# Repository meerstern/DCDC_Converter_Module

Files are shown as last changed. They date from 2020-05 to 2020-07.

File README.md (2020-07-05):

# DCDC_Converter_Module
Non-insulated boost type DCDC Converter Module with ADP1612 (1.8~5.5V -> +15/-15V)

## 概要 
  * [ADP1612スイッチングコンバータ][1]を使用した昇圧電源です
  * 1.8V~5.5Vの入力で±15.1Vの出力が得られます
  * スイッチング周波数が1.3MHzと高いため、AD変換用電源やオーディオ向け電源に最適です
  * [シングル出力のスイッチングコンバータで両電源を得る(PDF,P.21電源回路参照)][2]ことでコンバータICコストの削減が可能です
  * 出力はR2,R5で決定され、デフォルトは±15.1Vで固定されています
  * 出力有効ENは内部プルアップされているため、未接続orVIN接続で出力ONします
  * それぞれ最大200mA程度の出力を得られます  
  * サイズ40mm x30mm、M3x2、間隔22mm  
  * Ni-MH電池2本2.4V電源供給、負荷100ｍAの場合、Peak-Peakで30~50mV前後、RMSで30mV前後のリップルです
    ※負荷や測定条件によって異なるため、性能を保証するものではありません  

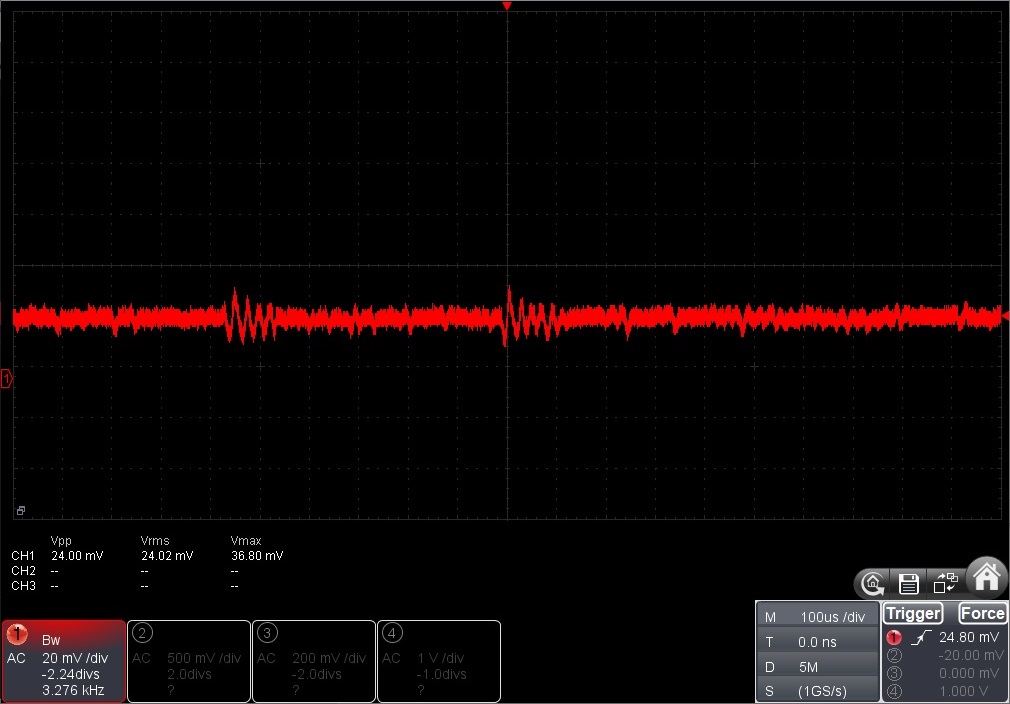
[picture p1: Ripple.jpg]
  
  
## 注意
  * ±15Vで両側に同じような負荷を接続してください
  * +15V側のみを電圧フィードバックする回路のため、負荷のアンバランスで出力電圧が不安定になる場合があります  
  * リップルを更に低減させるためには必要に応じて負荷側にコンデンサやフィルタを実装してください  

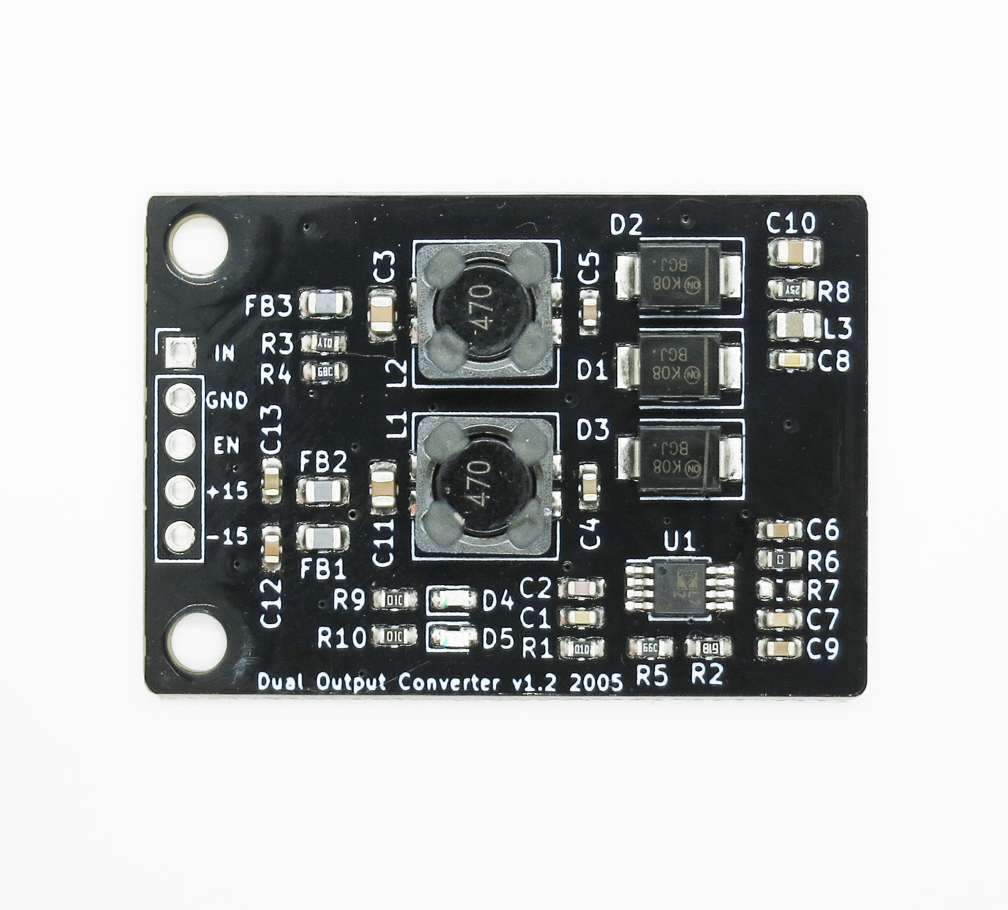
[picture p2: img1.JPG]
  
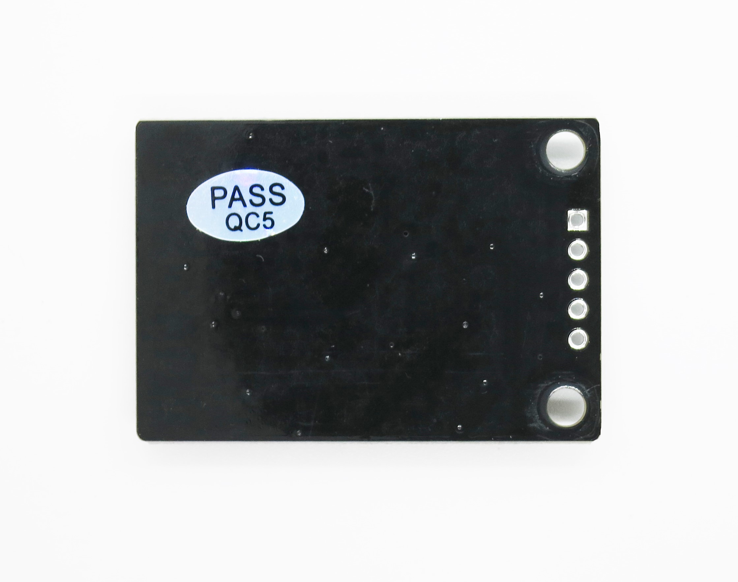
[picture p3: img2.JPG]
   

[1]: https://www.analog.com/jp/products/adp1612.html
[2]: https://www.analog.com/media/en/technical-documentation/data-sheets/ADAS3023.pdf

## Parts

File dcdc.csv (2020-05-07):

ID | 参照記号 | パッケージ | 数 | 名称 | Supplier and ref
1 | R2 | R_0603_1608Metric | 1 | 4.22k
2 | C13,C12,C9,C5,C4,C6 | C_0603_1608Metric | 6 | 1u
3 | R8 | R_0603_1608Metric | 1 | 1.8
4 | R3 | R_0603_1608Metric | 1 | 1
5 | L2,L1 | SRF0703 | 2 | 33uH
6 | H2,H1 | MountingHole_3.2mm_M3 | 2 | MountingHole
7 | L3 | L_0805_2012Metric | 1 | 1u
8 | C11,C10,C3 | C_0805_2012Metric | 3 | 10u
9 | C8 | C_0603_1608Metric | 1 | 2.2u
10 | C7 | C_0603_1608Metric | 1 | 0.1u
11 | U1 | MSOP-8_3x3mm_P0.65mm | 1 | ADP1612/ADP1613
12 | R10,R9 | R_0603_1608Metric | 2 | 10k
13 | R7 | R_0603_1608Metric | 1 | NM
14 | R6 | R_0603_1608Metric | 1 | 0
15 | R5 | R_0603_1608Metric | 1 | 47.5k
16 | R4 | R_0603_1608Metric | 1 | 50k
17 | R1 | R_0603_1608Metric | 1 | 100k
18 | J1 | PinHeader_1x05_P2.54mm_Vertical | 1 | Conn_01x05
19 | FB3,FB2,FB1 | L_0805_2012Metric | 3 | Ferrite_Bead_Small
20 | D5,D4 | D_0603_1608Metric | 2 | LED
21 | D3,D2,D1 | D_SMB | 3 | D_Schottky_ALT
22 | C2 | C_0603_1608Metric | 1 | 10p
23 | C1 | C_0603_1608Metric | 1 | 12n

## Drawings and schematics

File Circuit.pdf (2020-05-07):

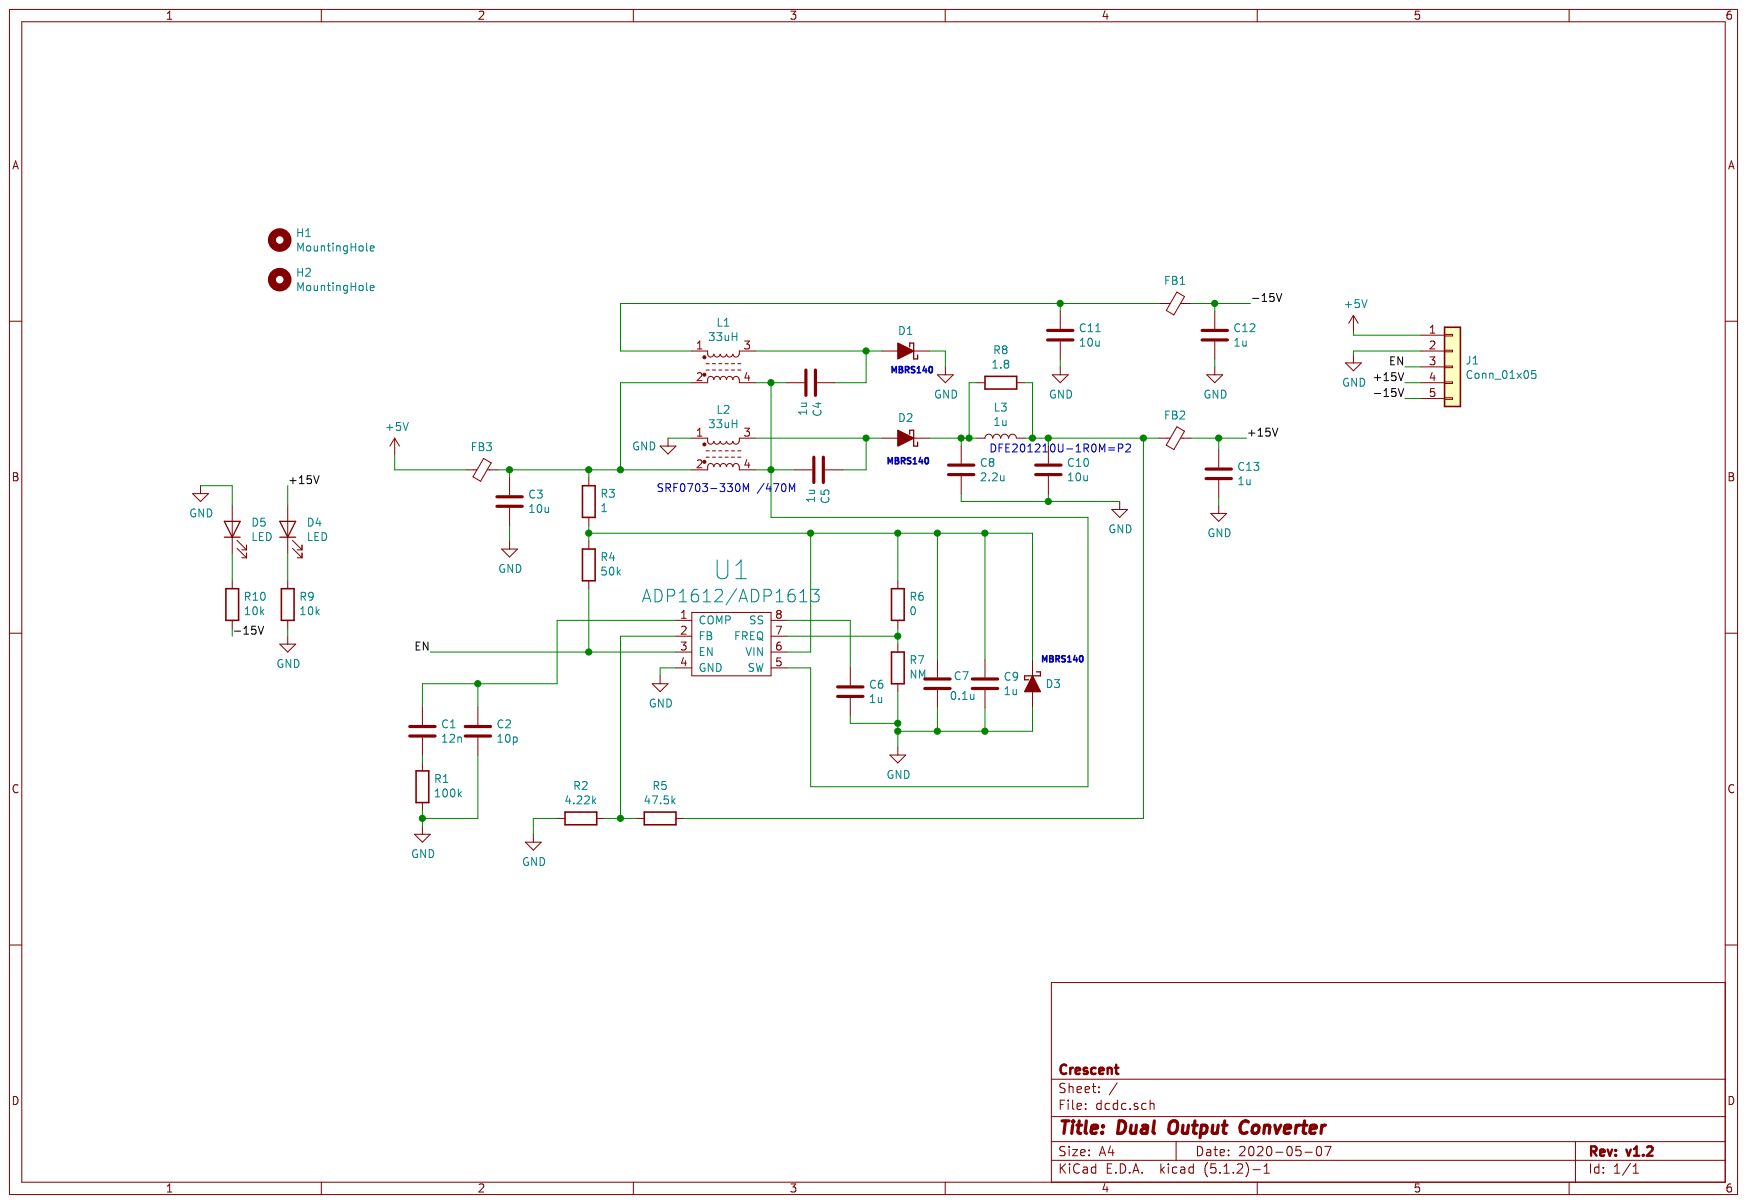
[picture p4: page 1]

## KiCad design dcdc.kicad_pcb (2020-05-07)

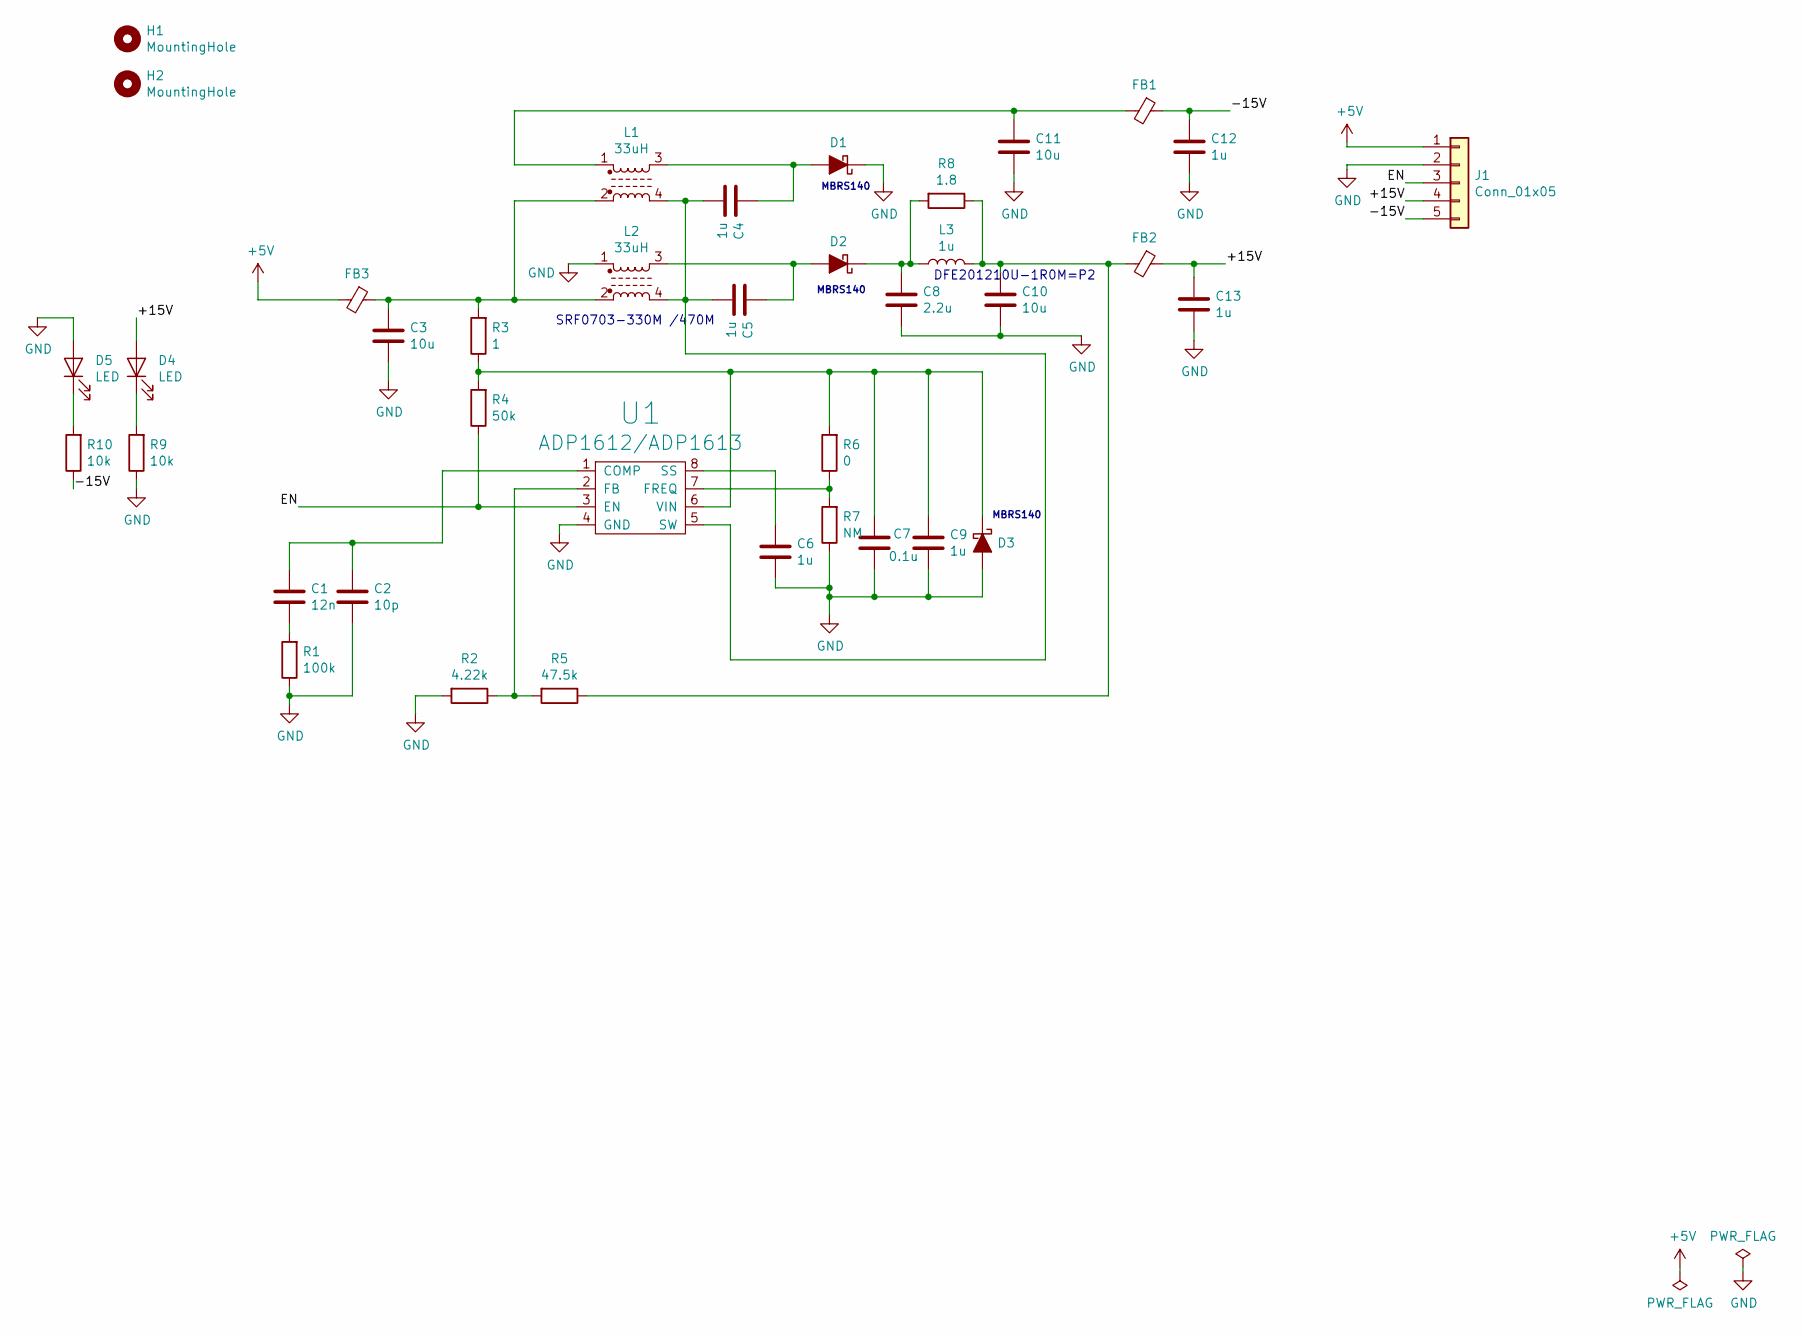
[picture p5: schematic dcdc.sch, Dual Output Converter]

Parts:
C1: 12n; C_0603_1608Metric
C2: 10p; C_0603_1608Metric
C3, C10, C11: 10u; C_0805_2012Metric
C4, C5, C6, C9, C12, C13: 1u; C_0603_1608Metric
C7: 0.1u; C_0603_1608Metric
C8: 2.2u; C_0603_1608Metric
D1, D2, D3: D_Schottky_ALT; D_SMB
D4, D5: LED; D_0603_1608Metric
FB1, FB2, FB3: Ferrite_Bead_Small; L_0805_2012Metric
H1, H2: MountingHole; MountingHole_3.2mm_M3
J1: Conn_01x05; PinHeader_1x05_P2.54mm_Vertical
L1, L2: 33uH; SRF0703
L3: 1u; L_0805_2012Metric
R1: 100k; R_0603_1608Metric
R2: 4.22k; R_0603_1608Metric
R3: 1; R_0603_1608Metric
R4: 50k; R_0603_1608Metric
R5: 47.5k; R_0603_1608Metric
R6: 0; R_0603_1608Metric
R7: NM; R_0603_1608Metric
R8: 1.8; R_0603_1608Metric
R9, R10: 10k; R_0603_1608Metric
U1: ADP1612/ADP1613; MSOP-8_3x3mm_P0.65mm

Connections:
+5V: FB3.2, J1.1
/+15V: C13.1, D4.2 (A), FB2.1, J1.4
/-15V: C12.1, FB1.1, J1.5, R10.1
/EN: J1.3, R4.1, U1.3 (EN)
GND: C2.2, C3.2, C6.2, C7.2, C8.2, C9.2, C10.2, C11.2, C12.2, C13.2, D1.1 (K), D3.2 (A), D5.2 (A), J1.2, L2.1, R1.1, R2.2, R7.1, R9.1, U1.4 (GND)
unnamed: C1.1, C2.1, U1.1 (COMP)
unnamed: C1.2, R1.2
unnamed: C3.1, FB3.1, L1.2, L2.2, R3.2
unnamed: C4.1, D1.2 (A), L1.3
unnamed: C4.2, C5.2, L1.4, L2.4, U1.5 (SW)
unnamed: C5.1, D2.2 (A), L2.3
unnamed: C6.1, U1.8 (SS)
unnamed: C7.1, C9.1, D3.1 (K), R3.1, R4.2, R6.2, U1.6 (VIN)
unnamed: C8.1, D2.1 (K), L3.1, R8.2
unnamed: C10.1, FB2.2, L3.2, R5.1, R8.1
unnamed: C11.1, FB1.2, L1.1
unnamed: D4.1 (K), R9.2
unnamed: D5.1 (K), R10.2
unnamed: R2.1, R5.2, U1.2 (FB)
unnamed: R6.1, R7.2, U1.7 (FREQ)

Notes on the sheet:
MBRS140
SRF0703-330M /470M
DFE201210U-1R0M=P2

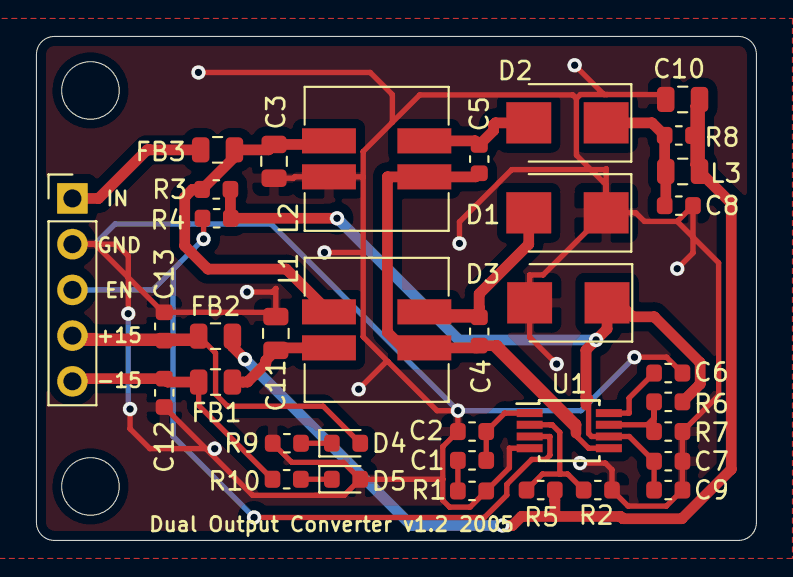
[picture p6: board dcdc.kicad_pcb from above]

Board: 2 copper layers, 40.0 x 28.0 mm, 38 parts (0 on the bottom side), 20 nets.
